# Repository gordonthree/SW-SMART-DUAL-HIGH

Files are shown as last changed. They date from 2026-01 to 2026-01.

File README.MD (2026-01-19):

# Dual High Side Smart Switch Node
* STM32G071 Microcontroller on board
* Dual BTS7002 Profet Smart Switches for high side loads, rated at 20 amps
* Microchip MCP2562 isolated CAN bus transceiver
* Voltage divider to monitor supply voltage
* Switch current monitoring and diagnostics
* Three position screw terminal block for CAN bus connection
* Three pos. screw terminal block for power-out, middle terminal is NC
* Heavy duty terminal block connectors for power in
* Headers for SWLINK programming and USART1 debug serial port

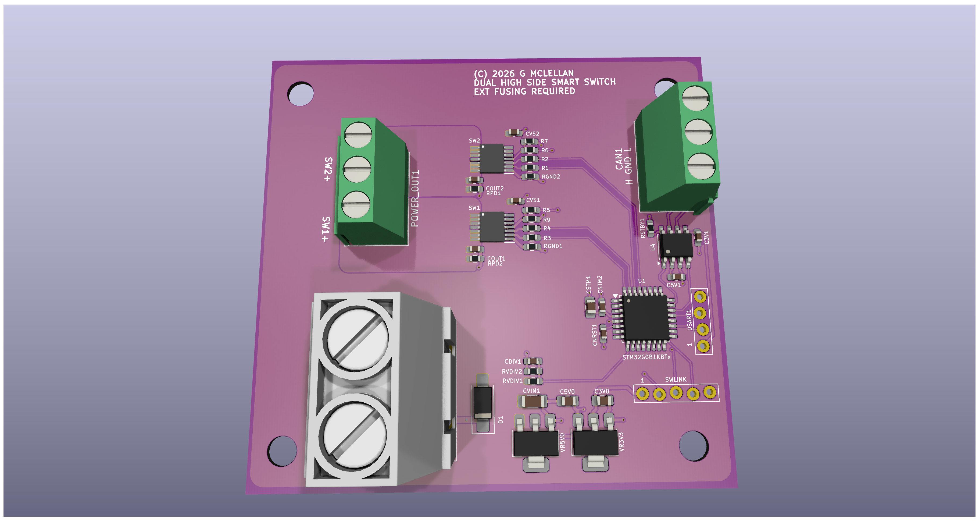
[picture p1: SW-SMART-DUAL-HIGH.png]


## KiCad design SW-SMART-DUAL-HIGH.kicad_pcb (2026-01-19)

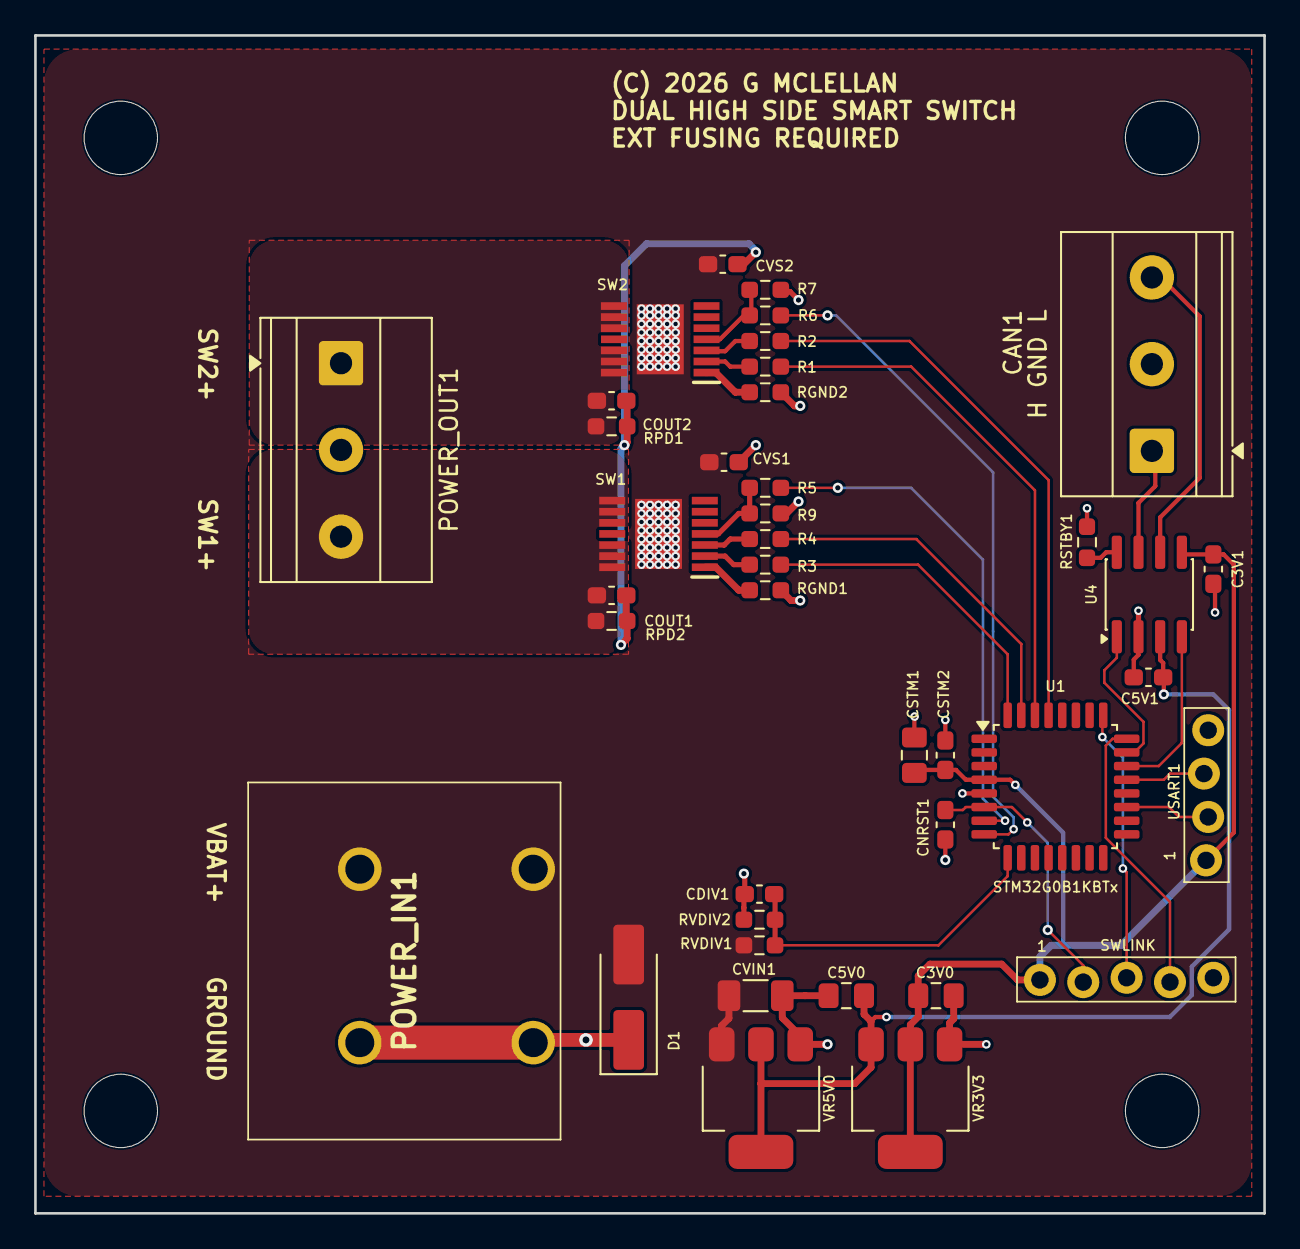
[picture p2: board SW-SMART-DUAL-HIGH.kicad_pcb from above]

Board: 2 copper layers, 72.0 x 69.0 mm, 44 parts (0 on the bottom side), 31 nets.

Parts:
C3V0, C5V0: 10u; C_0805_2012Metric_Pad1.18x1.45mm_HandSolder
C3V1, C5V1: 100n; C_0603_1608Metric_Pad1.08x0.95mm_HandSolder
CAN1: H GND L; TerminalBlock_Phoenix_MKDS-1,5-3-5.08_1x03_P5.08mm_Horizont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
CDIV1: 100n; C_0603_1608Metric_Pad1.08x0.95mm_HandSolder
CNRST1: 100n; C_0603_1608Metric_Pad1.08x0.95mm_HandSolder
COUT1, COUT2: 10n; C_0603_1608Metric_Pad1.08x0.95mm_HandSolder
CSTM1: 4u7; C_0805_2012Metric_Pad1.18x1.45mm_HandSolder
CSTM2: 100n; C_0603_1608Metric_Pad1.08x0.95mm_HandSolder
CVIN1: 10u; C_1206_3216Metric_Pad1.33x1.80mm_HandSolder
CVS1, CVS2: 68n; C_0603_1608Metric_Pad1.08x0.95mm_HandSolder
D1: 33V; D_SMA_Handsoldering
H1, H2, H3, H4: M4 4.3mm; MountingHole_4.3mm_M4
J1: SWLINK; 1x05_P2.54mm_Locking
J2: USART1; 1x04_P2.54mm_Locking
POWER_IN1: PWRIN; VP0265840000G
POWER_OUT1: TerminalBlock_Phoenix_MKDS-1,5-3-5.08_1x03_P5.08mm_Horizont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
R1, R2, R3, R4: 4K7; R_0603_1608Metric_Pad0.98x0.95mm_HandSolder
R5, R6: 10K; R_0603_1608Metric_Pad0.98x0.95mm_HandSolder
R7, R9: 1K0; R_0603_1608Metric_Pad0.98x0.95mm_HandSolder
RGND1, RGND2: 47R; R_0603_1608Metric_Pad0.98x0.95mm_HandSolder
RPD1, RPD2: 47K; R_0603_1608Metric_Pad0.98x0.95mm_HandSolder
RSTBY1: 10K; R_0603_1608Metric_Pad0.98x0.95mm_HandSolder
RVDIV1: 4K7; R_0603_1608Metric_Pad0.98x0.95mm_HandSolder
RVDIV2: 1K0; R_0603_1608Metric_Pad0.98x0.95mm_HandSolder
SW1, SW2: BTS7002-1EPP; SOP65P600X115-15N
U1: STM32G0B1KBTx; LQFP-32_7x7mm_P0.8mm
U4: MCP2562-E-SN; SOIC-8_3.9x4.9mm_P1.27mm
VR3V3: NCV1117ST33; SOT-223-3_TabPin2
VR5V0: NCV1117ST50; SOT-223-3_TabPin2

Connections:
+3.3V: C3V0.1, C3V1.1, CSTM1.1, CSTM2.1, J1.1, J2.1, U1.4 (VDD), U4.5 (Vio), VR3V3.2 (VO)
+5V: C5V0.1, C5V1.1, U4.3 (VDD), VR3V3.3 (VI), VR5V0.2 (VO)
+12V: CVIN1.1, CVS1.1, CVS2.1, D1.2 (A2), POWER_IN1.1, POWER_IN1.2, RVDIV1.2, SW1.15 (VS), SW2.15 (VS), VR5V0.3 (VI)
/CAN1_RX: U1.22 (PA9/PA11), U4.4 (RXD)
/CAN1_TX: U1.23 (PA10/PA12), U4.1 (TXD)
/CAN_H: CAN1.1, U4.7 (CANH)
/CAN_L: CAN1.3, U4.6 (CANL)
/NRST: CNRST1.1, J1.2, U1.6 (PF2)
/SW1DEN: R4.1, U1.31 (PB7)
/SW1IN: R3.1, U1.32 (PB8)
/SW1IS: R5.1, U1.7 (PA0)
/SW1IS_PD: R5.2, R9.2, SW1.4 (IS)
/SW1OUT: COUT1.1, POWER_OUT1.3, RPD2.2, SW1.8 (OUT), SW1.9 (OUT), SW1.10 (OUT), SW1.12 (OUT), SW1.13 (OUT), SW1.14 (OUT)
/SW2DEN: R2.1, U1.29 (PB5)
/SW2IN: R1.1, U1.30 (PB6)
/SW2IS: R6.1, U1.8 (PA1)
/SW2IS_PD: R6.2, R7.2, SW2.4 (IS)
/SW2OUT: COUT2.1, POWER_OUT1.1, RPD1.2, SW2.8 (OUT), SW2.9 (OUT), SW2.10 (OUT), SW2.12 (OUT), SW2.13 (OUT), SW2.14 (OUT)
/SWCLK: J1.3, U1.25 (PA14)
/SWDIO: J1.4, U1.24 (PA13)
/USART1_RX: J2.3, U1.21 (PA10/UCPD1_DBCC2)
/USART1_TX: J2.2, U1.19 (PA9/UCPD1_DBCC1)
/VS: CDIV1.1, RVDIV1.1, RVDIV2.2, U1.9 (PA2)
GND: C3V0.2, C3V1.2, C5V0.2, C5V1.2, CAN1.2, CDIV1.2, CNRST1.2, COUT1.2, COUT2.2, CSTM1.2, CSTM2.2, CVIN1.2, CVS1.2, CVS2.2, D1.1 (A1), J1.5, J2.4, POWER_IN1.3, POWER_IN1.4, R7.1, R9.1, RGND1.2, RGND2.2, RPD1.1, RPD2.1, RSTBY1.1, RVDIV2.1, U1.5 (VSS), U4.2 (VSS), VR3V3.1 (GND), VR5V0.1 (GND)
unnamed: R4.2, SW1.3 (DEN)
unnamed: RGND1.1, SW1.1 (GND)
unnamed: R3.2, SW1.2 (IN)
unnamed: R2.2, SW2.3 (DEN)
unnamed: RGND2.1, SW2.1 (GND)
unnamed: R1.2, SW2.2 (IN)
unnamed: RSTBY1.2, U4.8 (STBY)

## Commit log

2026-01-19 rework existing design with different switch configuration
    [SW-SMART-DUAL-HIGH.kicad_pcb, SW-SMART-DUAL-HIGH.kicad_sch]
2026-01-19 lots of rework to adapt previous layout to new switch configuration
    [SW-SMART-DUAL-HIGH.kicad_pcb, SW-SMART-DUAL-HIGH.kicad_sch]
2026-01-19 fix supply plane pour alignment
    [SW-SMART-DUAL-HIGH.kicad_pcb]
2026-01-19 schematic tweaks
    [SW-SMART-DUAL-HIGH.kicad_sch]

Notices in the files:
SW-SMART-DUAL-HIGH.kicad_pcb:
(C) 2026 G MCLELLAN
